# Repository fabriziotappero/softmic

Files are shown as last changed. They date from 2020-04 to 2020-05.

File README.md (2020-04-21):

# Software-Defined Microphone

This is the home of *Software-Defined Microphone*, a quite special
high-quality wireless microphone designed to allow you to focus on the artistic
aspect of sound recording.

The basic idea is a microphone that includes all the necessary on-board 
software so that compression, noise reduction, volume control is magically done
by the microphone itself. The ultimate goal of this microphone is to let the
microphone take care of the technicalities so that you can concentrate on the 
artistic aspect of sound recording.

In this picture you can see a the first prototype of *Software-Defined Microphone*.

<p align="center">
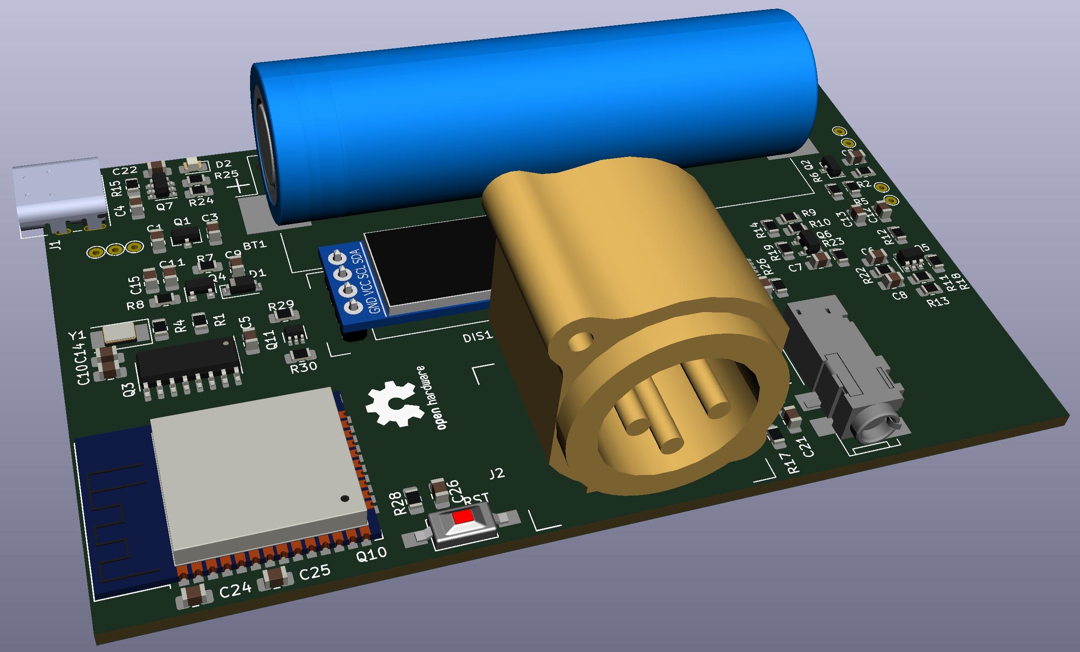
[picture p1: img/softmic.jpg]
  
</p>

*Software-Defined Microphone* is completely  open source: schematics, circuit 
simulations, mechanical drawings and software code.

## Repository Folder Structure
This is the folder structure of this project.
```
root
│   README.md               The file your are reading
│   license.md              License file    
└───sch                     Schematics and PCB fab files done in KiCad
│   │   softmic.pro
│   │   softmic.sch
│   │   softmic.kicad_pcb
│   └───lib                 Kicad library files
│   └───pdf                 IC data sheets
└───sim                     Simulated circuits in LT Spice
│   │   softmic-sim.asc
│   └───lib                 LT Spice library  
└───src                     Micropython ESP32 code
└───mec                     Mechanical parts designed in Blender
└───img                     Various images
└───tmp                     generic data sheets and additional info
```
## Starting point
I actually own a [Samson C02](https://www.amazon.com/s?k=samsons+c02) condenser
microphone that I use together with a [Tascam DR-40](https://www.amazon.com/s?k=tascam+dr-40).
[Here](https://soundcloud.com/cinema_sound/samson-c02-dx-pop-filter) 
an example of what the Samson C02 sounds like 
and following, the picture of the inside of my Samson C02.

<p align="center">
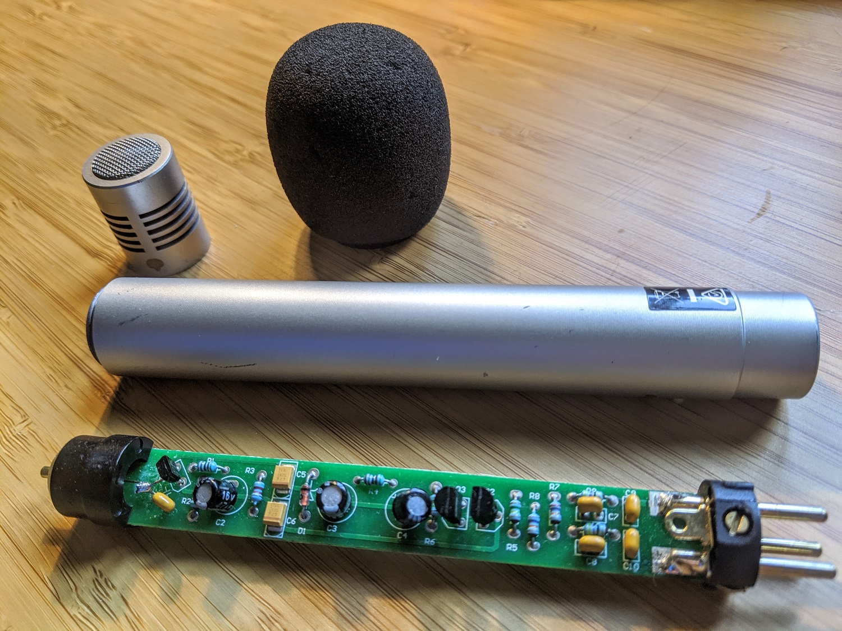
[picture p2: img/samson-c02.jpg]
  
</p>
Here you can see the actual schematic of the Samson C02 (courtesy of *the Internet*). 
Nothing really mind-blowing but functional.
<p align="center">
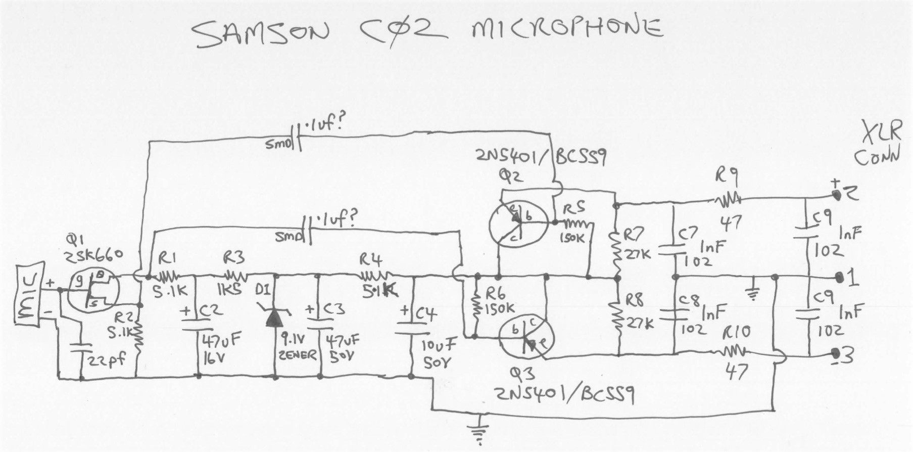
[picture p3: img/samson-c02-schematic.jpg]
  
</p>

For the time being this is the starting point of this project. The objective of 
this project is to make something of a similar quality but *software-oriented*.

## Microphone Capsule
This microphone is designed to function with an **electret capsule** similar to the
[Primo EM173](sch/pdf/PrimoEM173.pdf), an
electret capsule with an internal FET. For some additional flexibility the use of
a simpler electret capsule without FET (e.g. the 
[Transsound TSB160A](img/TSB160A.jpg) from the 
Samson C02) will be possible too.

## Microphone System Design
Let us see a detailed list of features of this microphone. Some of these features
are still unimplemented.

1. The microphone uses a standard **electret microphone capsule** with a standard 
 internal FET. The use of a electret microphone without FET is possible too.

2. a traditional 3.5mm stereo headphone jack output (unbalanced line out) allows 
the microphone to be connected to a pair of standard headphones for monitoring 
purposes.

3. A standard XLR connector offers a balanced audio output. This allows this
microphone to be interfaced with any traditional audio equipment.

4. When provided externally via the XLR connector, phantom power can power the 
microphone. (UNIMPLEMENTED)

5. A Bluetooth/WiFi output allows to connect without cables to a camera, 
smartphone or PC.

6. When using Bluetooth/WiFi, multiple microphones can be all connected among
them. (UNIMPLEMENTED)

7. An internal 1-cell lithium battery can power the microphone for approximately
10h. This battery is rechargeable via a USB-C connector.

4. When provided externally via the XLR connector, phantom power can recharge the 
internal lithium battery. (UNIMPLEMENTED)

8. The microphone is equipped with a fairly powerful dual-core
processor re-programmable over the WiFi connection or over USB-C. The processor
programming is done in [Micropython](https://micropython.org/).

9. To ease connectivity with other accessories the microphone is equipped
with one-does-it-all small multi-pin connector. (UNIMPLEMENTED)

10. A spring connector similar to the 
[Coda Systems PCB sprint connector](img/codaSystemsSpringConn.jpg) allows the 
microphone to be connected to or power other accessories. (UNIMPLEMENTED)

11. A small LCD outputs all necessary microphone information.

12. Few push buttons allow to interact with the microphone.

13. The internal ESP32 dual-core processor allows the realtime processing of the
audio signal coming in. (UNIMPLEMENTED)

## Circuit Schematics
In the following figure you can see the KiCad schematic of softmic done in KiCad.

<p align="center">
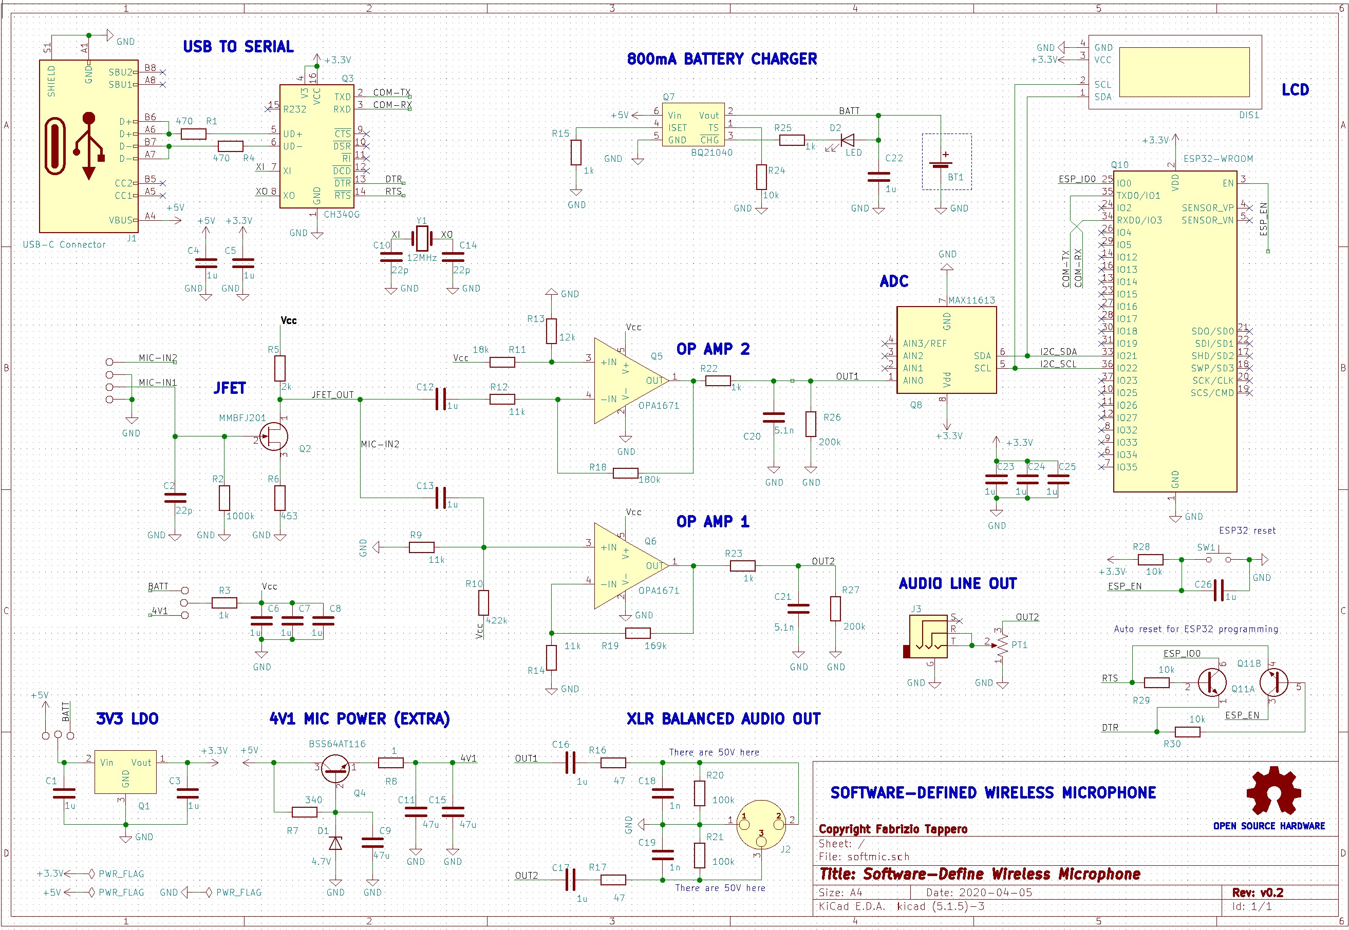
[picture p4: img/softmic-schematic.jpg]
  
</p>

## Mechanical Parts
A full fledged microphone is not only made of its electronics, mechanical parts 
are equally important.

Any mechanical parts in this projects are made with non-destructive modeling 
using [Blender](https://www.blender.org) version 2.8. 
For a quick start have a look at this 
[great tutorial](https://www.youtube.com/watch?v=WzwmkYhlrcQ).

## License
Copyright (c) 2020 Fabrizio Tappero

Permission is hereby granted, free of charge, to any person obtaining a copy of 
this software and associated documentation files (the "Software"), to deal in 
the Software without restriction, including without limitation the rights to 
use, copy, modify, merge, publish, distribute, sublicense, and/or sell copies 
of the Software, and to permit persons to whom the Software is furnished to do 
so, subject to the following conditions:

The above copyright notice and this permission notice shall be included in all 
copies or substantial portions of the Software.

THE SOFTWARE IS PROVIDED "AS IS", WITHOUT WARRANTY OF ANY KIND, EXPRESS OR 
IMPLIED, INCLUDING BUT NOT LIMITED TO THE WARRANTIES OF MERCHANTABILITY, 
FITNESS FOR A PARTICULAR PURPOSE AND NONINFRINGEMENT. IN NO EVENT SHALL THE 
AUTHORS OR COPYRIGHT HOLDERS BE LIABLE FOR ANY CLAIM, DAMAGES OR OTHER 
LIABILITY, WHETHER IN AN ACTION OF CONTRACT, TORT OR OTHERWISE, ARISING 
FROM, OUT OF OR IN CONNECTION WITH THE SOFTWARE OR THE USE OR OTHER 
DEALINGS IN THE SOFTWARE.

## References
A lot of microphone and microphone-related products and devices exists out there.
Here is what it can be considered a good starting point.

[Electret microphone](ttps://sound-au.com/articles/mic-electret.htm) and their
[electret Capsule](http://www.firstpr.com.au/rwi/mics/2009-09-a/).

[Microphone capsule Manufacturer](https://www.jlielectronics.com/microphone-capsules/?sort=pricedesc)
and one more [ capsule Manufacturer](https://microphone-parts.com/collections/capsules).

[Extensive RODE guy lecturer](https://www.youtube.com/watch?v=yKOH0DyRWRU&list=PLHoGZ7nuFTo8VmQBhzZxl-qDEIN7T5Vt8).
and some [audio Microphone Kits](https://microphone-parts.com/collections/mod-kits).

[Electret Amplifier Circuits](http://xtremecircuits.blogspot.com/2012/09/compressor-for-electret-microphone.html).

Some Texas instruments IC, [here](https://www.ti.com/lit/an/sboa320a/sboa320a.pdf) and 
[here](http://www.ti.com/lit/ug/tidu765/tidu765.pdf).

if you google *TS971 based Electret Condenser Microphone Amplifier* you get:
[this](https://robbietrumpet.com/soundcatchers.net/studio_recording_sound.htm), 
[this](https://www.instructables.com/id/Modify-a-cheap-LDC-Condenser-microphone/), 
[this](http://www.sdiy.org/oid/mics/Schoeps.gif) and 
[this](http://www.zen22142.zen.co.uk/Circuits/Audio/ecmmic.htm).

[Some electret capsules](https://www.abcomponents.co.uk/product-category/electret-microphones/) and 
[this](https://micbooster.com/12-primo-microphone-capsules) and 
[this](https://micbooster.com/content/12-comparison-table-for-primo-microphone-capsules).

Very interesting [electret capsules](https://micbooster.com/primo-microphone-capsules/9-em173.html)
and [some more](https://micbooster.com/primo-microphone-capsules/8-primo-em172.html) plus the 
[very best electret capsule](http://www.micbooster.com/documents/EM173%20Oct%202011.pdf).

[Application Note about LSK489](http://www.linearsystems.com/lsdata/others/LSK489_Application_Note.pdf).

[Interesting capacity multiplier](http://www.audioimprov.com/AudioImprov/Mics/Entries/2014/12/18_Another_Chinese_mic_Circuit.html).

[Samson C02 internal circuit](http://www.audioimprov.com/AudioImprov/Mics/Entries/2015/4/23_Basic_FET_Microphone_Circuits.html).

[Popular Alice schematic](http://scotthelmke.com/alice-mic.html).

[How to bias a JFET](http://www.vishay.com/docs/70595/70595.pdf).

[Audio compressor](https://www.electroschematics.com/audio-compressor-agc/).

[Audio Op Amp IC from Texas Instrument](http://www.ti.com/lit/ds/symlink/opa1678.pdf).

Interesting [blog post](https://www.diyaudio.com/forums/equipment-and-tools/319784-search-ultra-quality-electret-mic-interface-circuit.html) and 
[here](https://www.electronics-lab.com/project/low-noise-mini-electret-microphone-preamplifier/),
[here](http://www.johncon.com/john/wm61a/) 
and [here](http://www.micbooster.com/documents/EM173%20Oct%202011.pdf).

[Interesting audio people](https://micbooster.com/)

[Interesting microphone case](https://eu.mouser.com/Wire-Cable/Wire-Cable-Management/Cable-Glands-Strain-Reliefs-Cord-Grips/_/N-fb8zo) and [one more](https://eu.mouser.com/datasheet/2/18/inhouse_Amphenol_C146%20Series_Accessories_VN16-1158081.pdf).

[Audio Preamp product](https://www.bhphotovideo.com/c/product/292989-REG/Sound_Devices_MM_1_MM_1_Single_Channel_Portable.html/overview) and one more 
[reference audio preamp](http://www.hiroshi.com.hk/en/product/detail/mini-microphone-pre-amplifier-23#.Xn4073Io_ws)
that I actually own.

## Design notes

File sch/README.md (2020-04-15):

Schematic files for the creation of the PCB done using the open-source software KICAD available from:

https://www.kicad-pcb.org/

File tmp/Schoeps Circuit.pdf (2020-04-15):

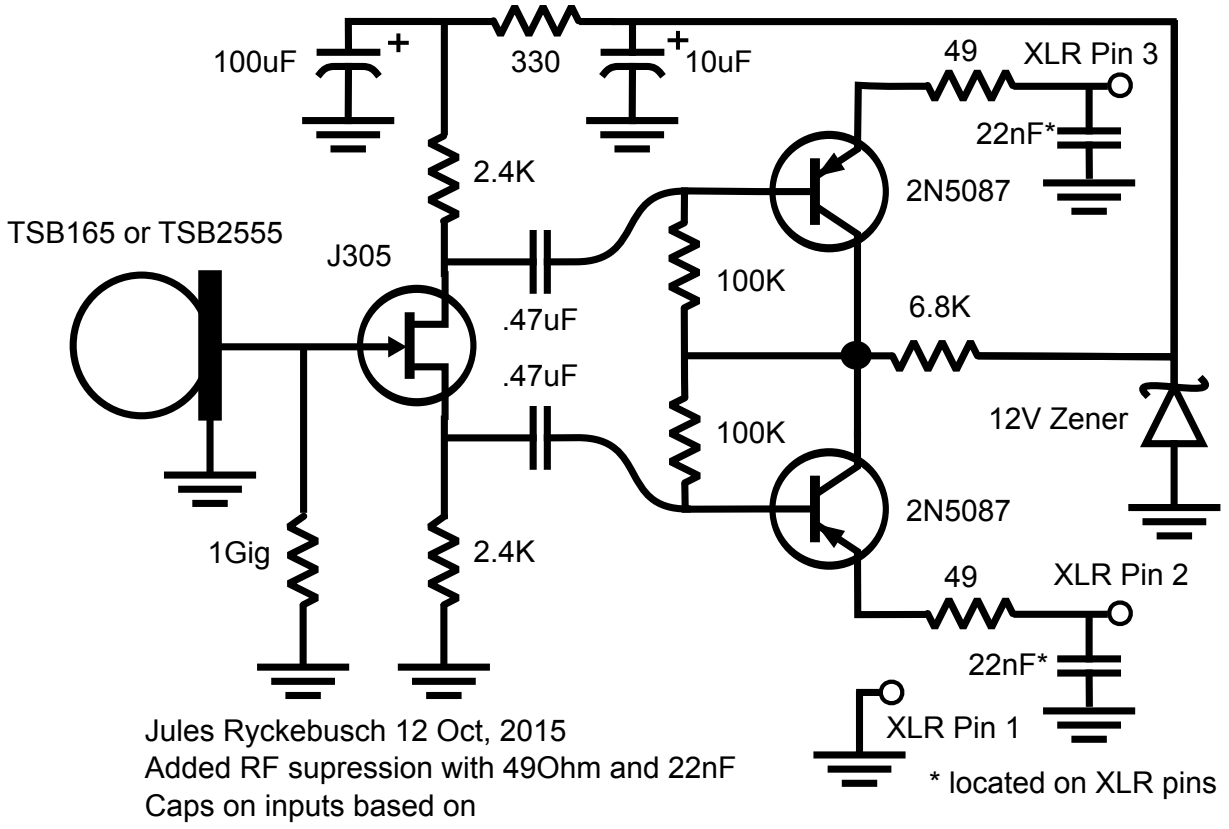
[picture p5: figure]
XLR Pin 1; XLR Pin 2; XLR Pin 3 100uF; 12V Zener; Jules Ryckebusch 12 Oct, 2015 Added RF supression with 49Ohm and 22nF Caps on inputs based on; * located on XLR pins; 1Gig; TSB165 or TSB2555

Scott Helmke "Alice" Mic Schoeps Circuit

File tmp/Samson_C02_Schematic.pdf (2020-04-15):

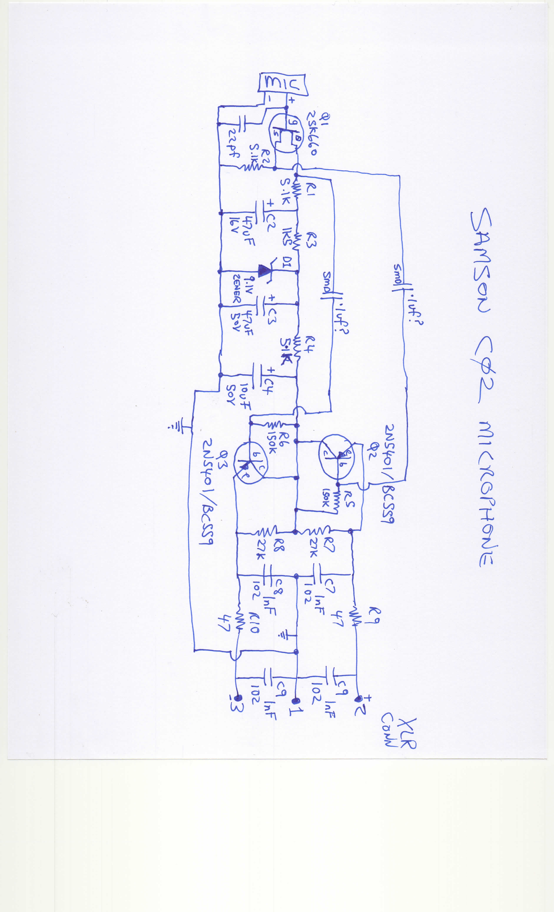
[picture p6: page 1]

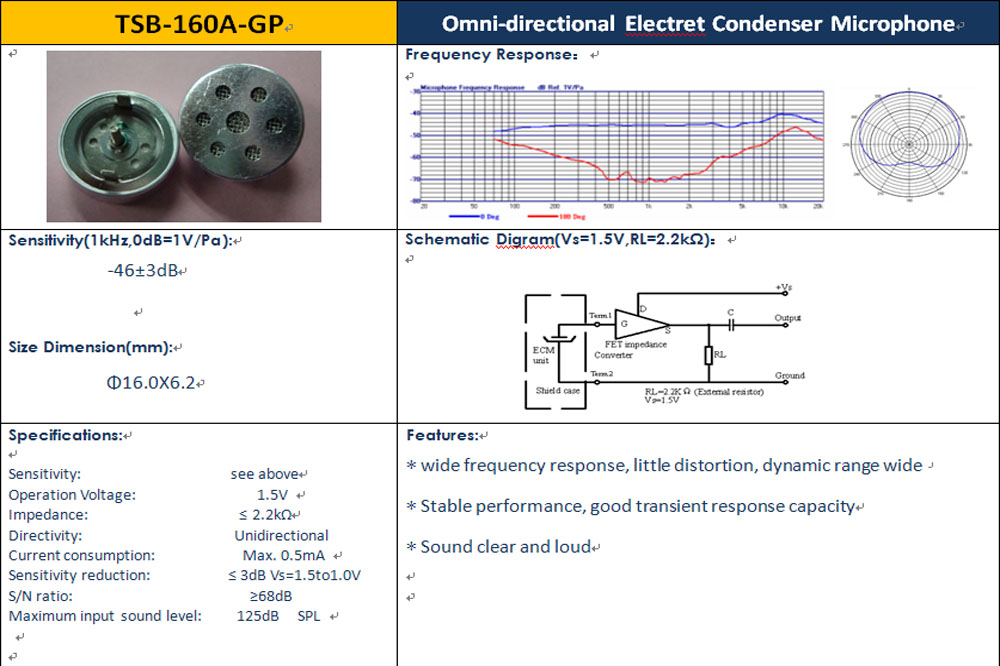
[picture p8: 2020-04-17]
img/TSB160A.jpg

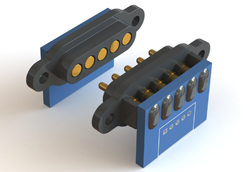
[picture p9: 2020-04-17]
img/codaSystemsSpringConn.jpg

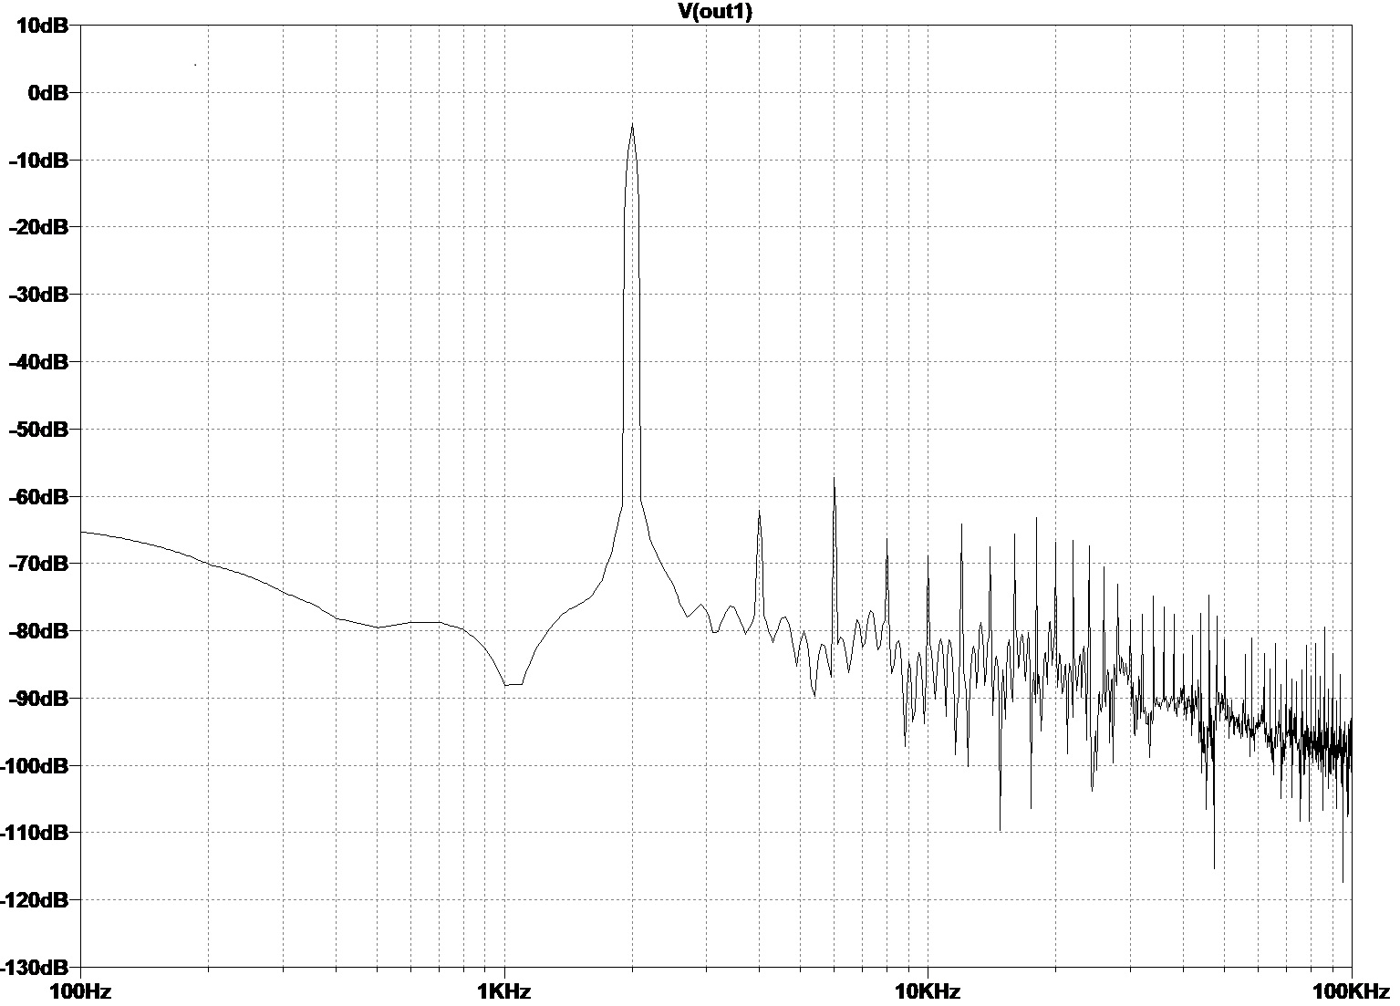
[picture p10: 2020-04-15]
sim/ALL-FFT.jpg

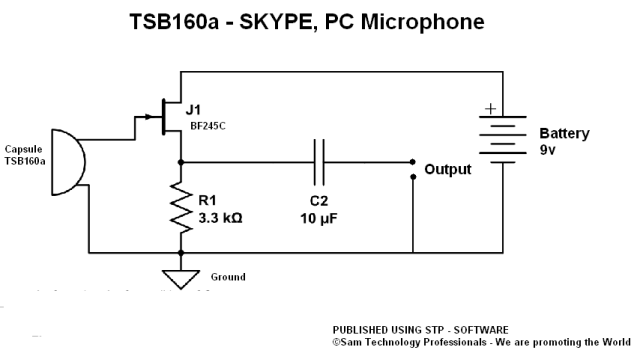
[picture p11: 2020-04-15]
tmp/TSB160A.png

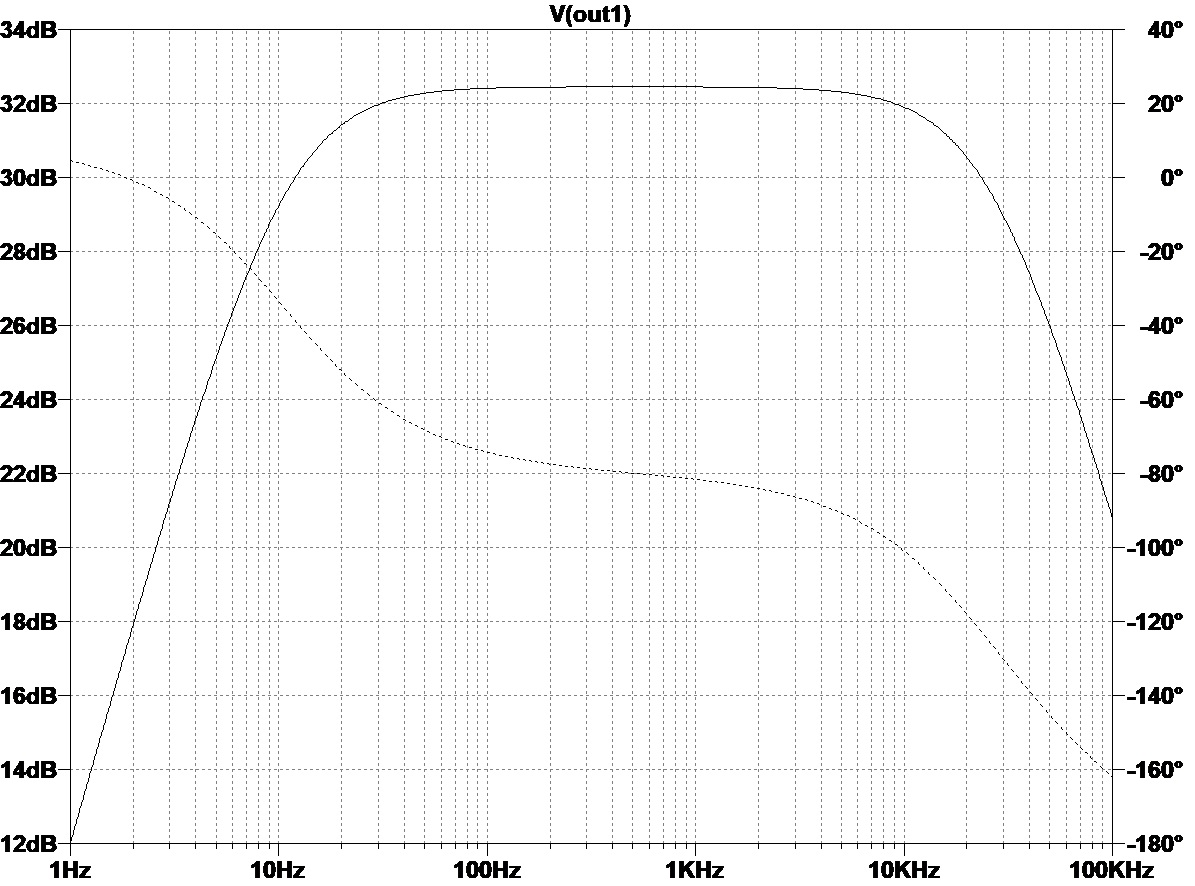
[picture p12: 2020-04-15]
sim/ALL-BW.jpg

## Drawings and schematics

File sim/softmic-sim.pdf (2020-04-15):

# Audio Pre Amplifier, 32dB gain, 20Hz to 20kHz at -1dB bandwidth

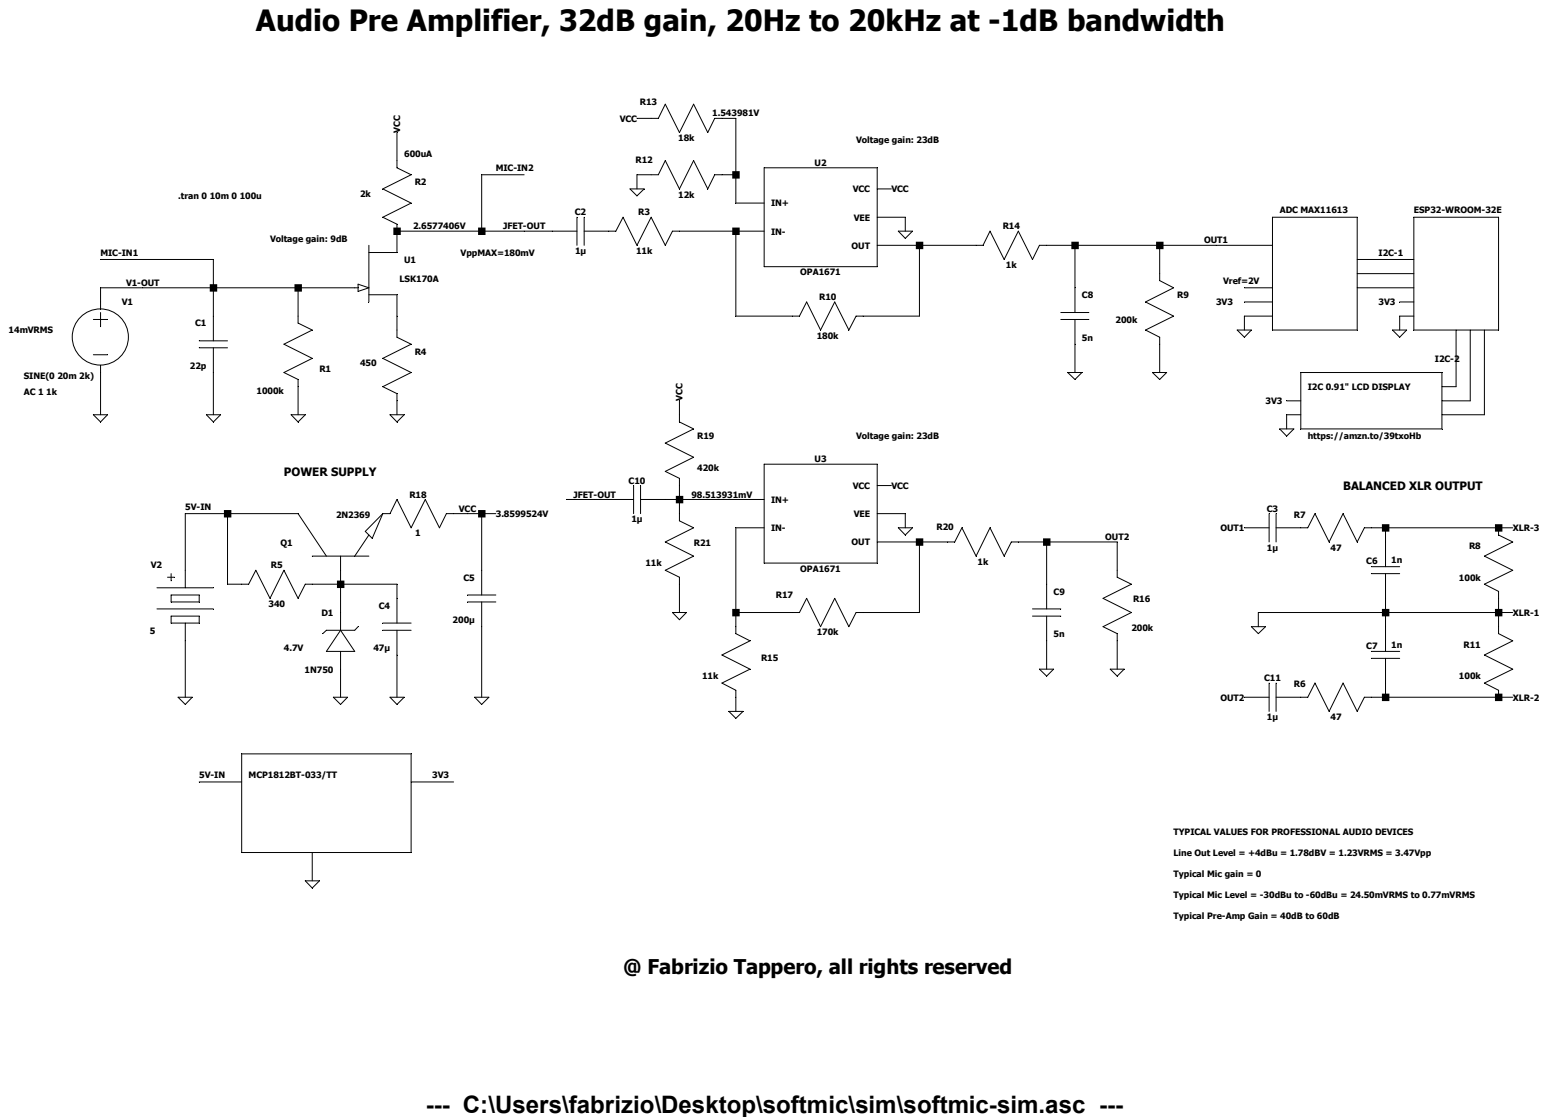
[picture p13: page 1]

TYPICAL VALUES FOR PROFESSIONAL AUDIO DEVICES

Typical Mic Level = -30dBu to -60dBu = 24.50mVRMS to 0.77mVRMS

Typical Pre-Amp Gain = 40dB to 60dB

@ Fabrizio Tappero, all rights reserved

--- C:\Users\fabrizio\Desktop\softmic\sim\softmic-sim.asc ---

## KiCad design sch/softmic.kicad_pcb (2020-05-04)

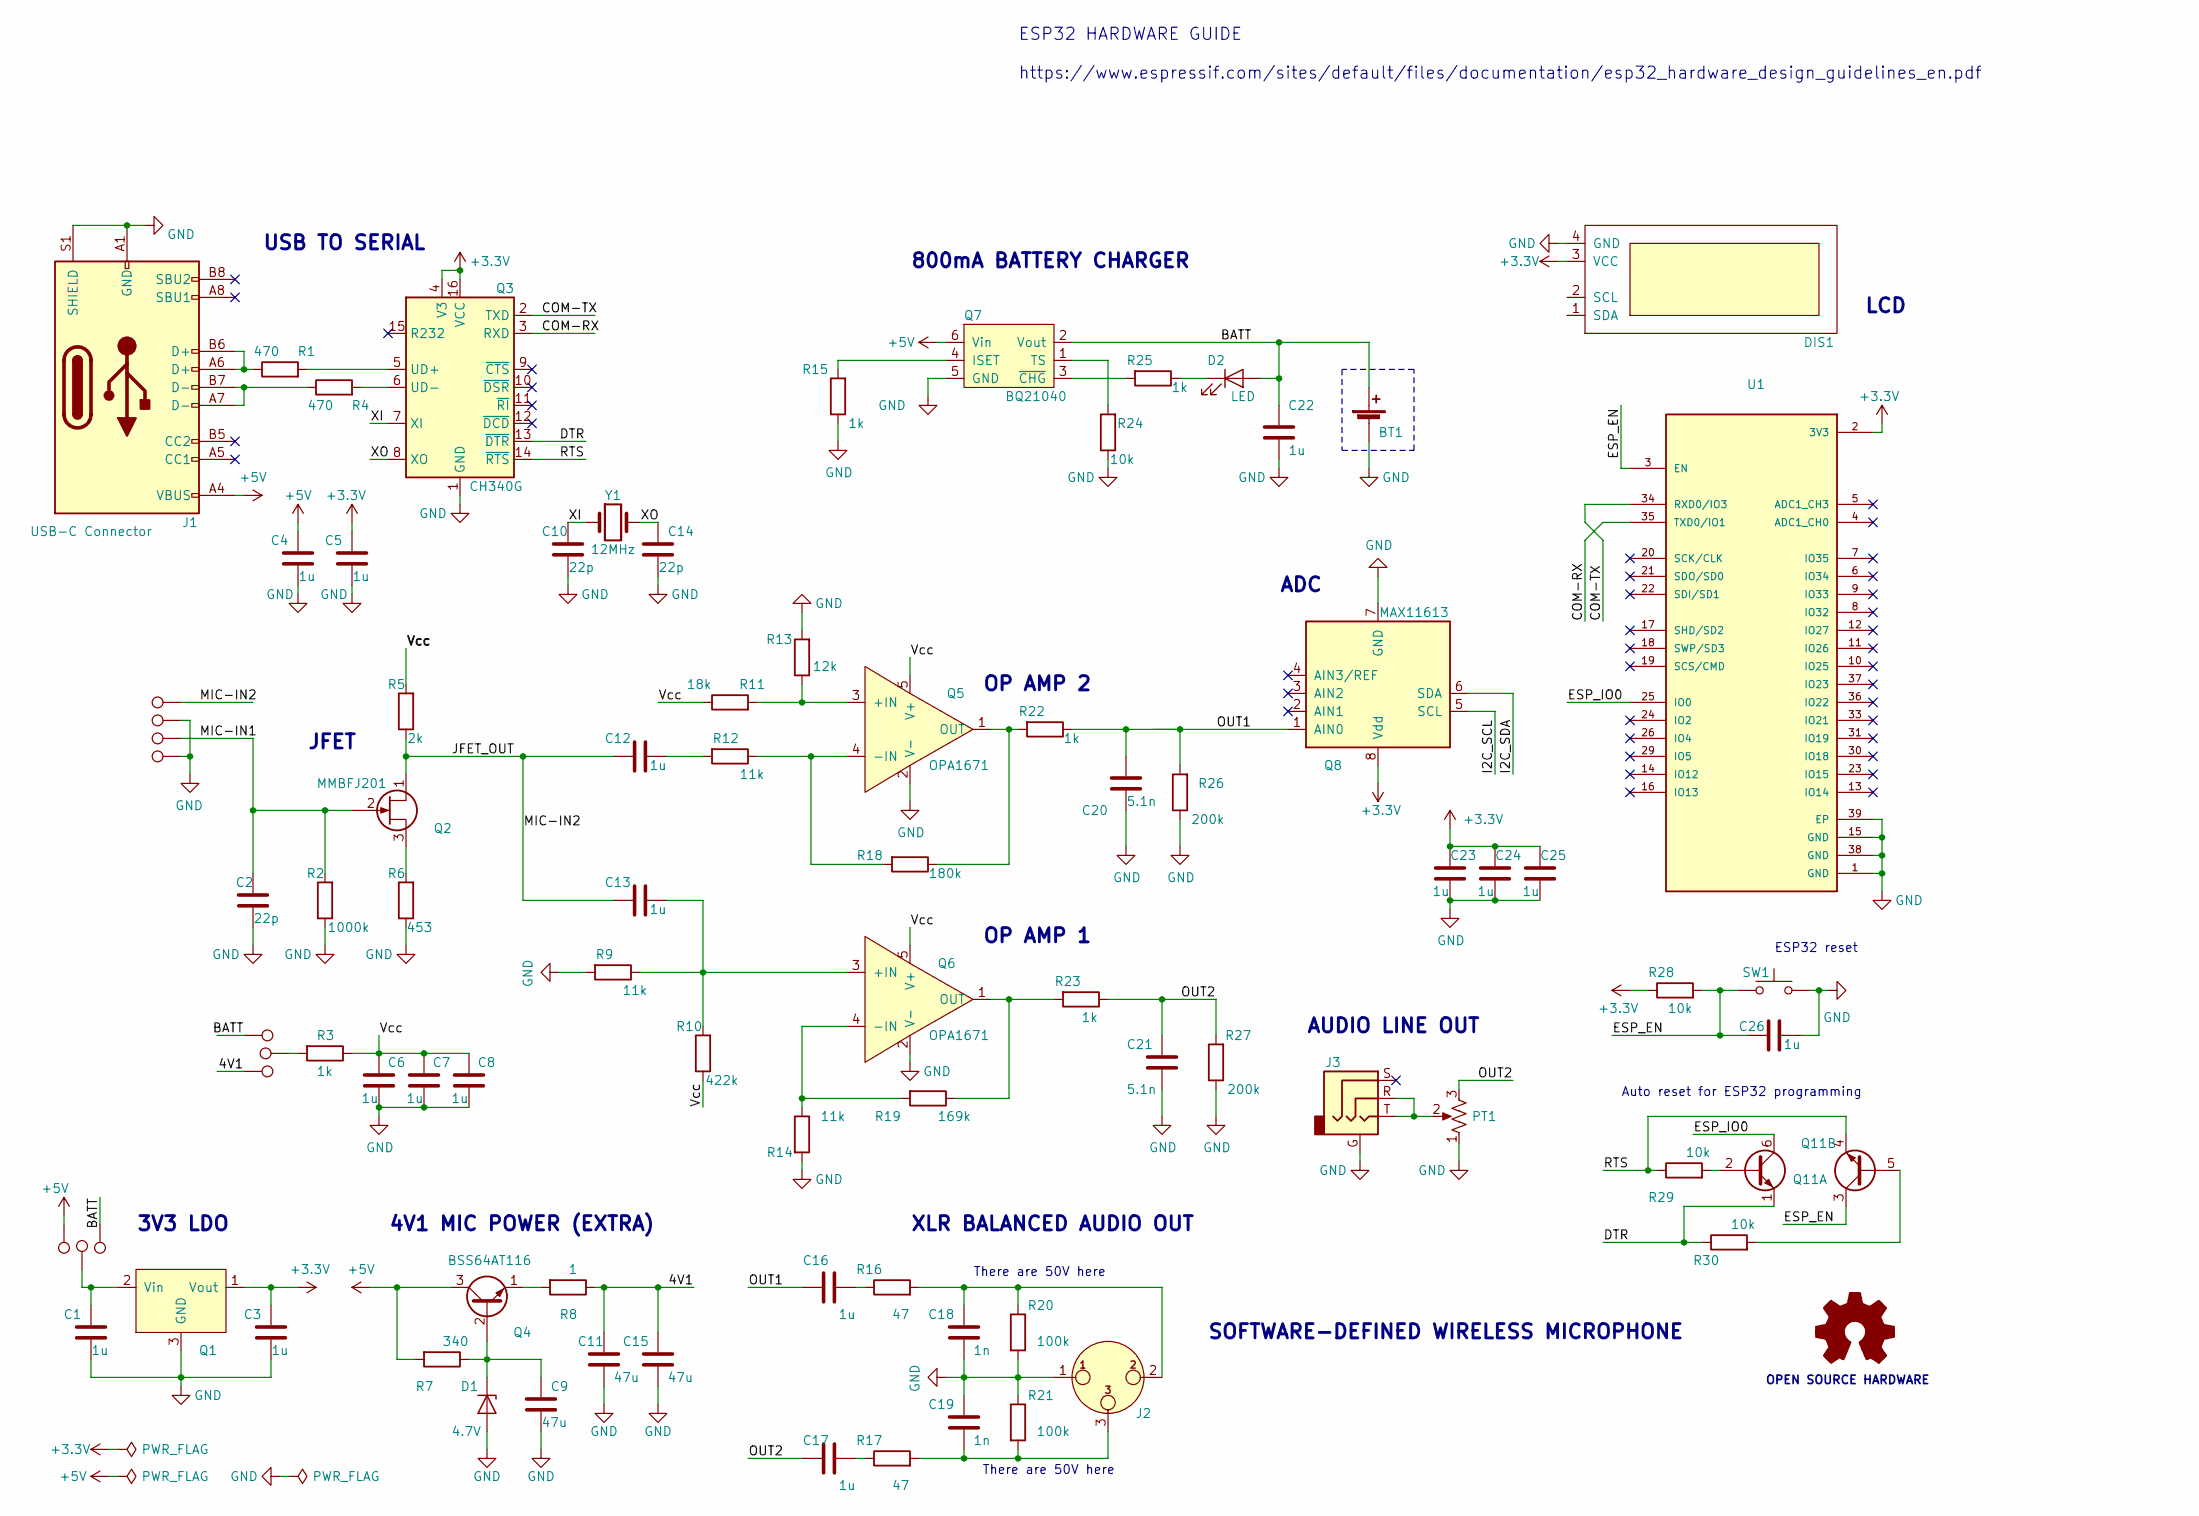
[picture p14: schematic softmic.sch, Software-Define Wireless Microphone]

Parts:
BT1: 1-Cell Litium Battery; BatteryHolder18650; Mouser PN none; Digikey PN none
C1, C3, C4, C5, C6, C7, C8, C12, C13, C16, C17, C22, C23, C24, C25, C26: 1u; C_0805_2012Metric_Pad1.15x1.40mm_HandSolder; MPN HMK212BC7105MGHT; Digikey PN none
C2, C10, C14: 22p; C_0805_2012Metric_Pad1.15x1.40mm_HandSolder; MPN none; Digikey PN none
C9, C11, C15: 47u; C_0805_2012Metric_Pad1.15x1.40mm_HandSolder; MPN LMK316BC6476ML-T; Digikey PN none
C18, C19: 1n; C_0805_2012Metric_Pad1.15x1.40mm_HandSolder; MPN none; Digikey PN none
C20, C21: 5.1n; C_0805_2012Metric_Pad1.15x1.40mm_HandSolder; MPN none; Digikey PN none
D1: 4.7V; D_SOD-123; MPN BZT52C4V7-E3-08; Digikey PN 112-BZT52C4V7-E3-08CT-ND
D2: LED; LED_0805_2012Metric_Pad1.15x1.40mm_HandSolder; Mouser PN 710-150080RS75000; Digikey PN 732-4984-1-ND
DIS1: Oled_128_32; OLED-0.91-128x32; MPN none; Digikey PN none
J1: USB-C Connector; USB_C_Receptacle_GCT_USB4085; MPN USB4085-GF-A; Digikey PN 2073-USB4085-GF-ACT-ND
J2: XLR-OUT; XLR-NC3MAAH-1; MPN NC3MAAH-1; Digikey PN none
J3: AudioJack 3.5mm; SJ-43514-SM; MPN SJ-43514-SMT-TR; Digikey PN CP-43514SJCT-ND
P1, P2, P3, P8, P9: 4V1; TestPoint_THTPad_D1.5mm_Drill0.7mm; MPN none; Digikey PN none
P4, P5, P6, P7: none; TestPoint_THTPad_D1.5mm_Drill0.7mm; MPN none; Digikey PN none
P10: VccPad; TestPoint_THTPad_D1.5mm_Drill0.7mm; MPN none; Digikey PN none
PT1: 200k; Potentiometer_Bourns_3224W_Vertical; MPN PVG3G204C01R00; Digikey PN PVG3G204C01R00
Q1: MCP1812BT-033; SOT-23; MPN MCP1812BT-033/TT; Digikey PN MCP1812BT-033/TTTR-ND
Q2: MMBFJ201; SOT-23; MPN MMBFJ201; Digikey PN MMBFJ201CT-ND
Q3: CH340G; SOIC-16_3.9x9.9mm_P1.27mm; MPN CH340G; LCSC PN C14267
Q4: BSS64AT116; SOT-23; MPN BSS64AT116; Digikey PN BSS64AT116CT-ND
Q5, Q6: OPA1671; SOT-23-5; MPN OPA1671IDBVR; Digikey PN 296-OPA1671IDBVRCT-ND
Q7: BQ21040; SOT-23-6; MPN BQ21040DBVT; Digikey PN 296-44196-1-ND
Q8: MAX11613; MSOP-8_3x3mm_P0.65mm; MPN MAX11613EUA+T; Digikey PN MAX11613EUA+CT-ND
Q11: BC847BS-TP; SOT-363_SC-70-6; Mouser PN 833-BC847BS-TP
R1, R4: 470; R_0805_2012Metric_Pad1.15x1.40mm_HandSolder; MPN none; Digikey PN none
R2: 1000k; R_0805_2012Metric_Pad1.15x1.40mm_HandSolder; MPN none; Digikey PN none
R3, R15, R22, R23, R25: 1k; R_0805_2012Metric_Pad1.15x1.40mm_HandSolder; MPN none; Digikey PN none
R5: 2k; R_0805_2012Metric_Pad1.15x1.40mm_HandSolder; MPN none; Digikey PN none
R6: 453; R_0805_2012Metric_Pad1.15x1.40mm_HandSolder; MPN none; Digikey PN none
R7: 340; R_0805_2012Metric_Pad1.15x1.40mm_HandSolder; MPN none; Digikey PN none
R8: 1; R_0805_2012Metric_Pad1.15x1.40mm_HandSolder; MPN none; Digikey PN none
R9, R12, R14: 11k; R_0805_2012Metric_Pad1.15x1.40mm_HandSolder; MPN none; Digikey PN none
R10: 422k; R_0805_2012Metric_Pad1.15x1.40mm_HandSolder; MPN none; Digikey PN none
R11: 18k; R_0805_2012Metric_Pad1.15x1.40mm_HandSolder; MPN none; Digikey PN none
R13: 12k; R_0805_2012Metric_Pad1.15x1.40mm_HandSolder; MPN none; Digikey PN none
R16, R17: 47; R_0805_2012Metric_Pad1.15x1.40mm_HandSolder; MPN none; Digikey PN none
R18: 180k; R_0805_2012Metric_Pad1.15x1.40mm_HandSolder; MPN none; Digikey PN none
R19: 169k; R_0805_2012Metric_Pad1.15x1.40mm_HandSolder; MPN none; Digikey PN none
R20, R21: 100k; R_0805_2012Metric_Pad1.15x1.40mm_HandSolder; MPN none; Digikey PN none
R24, R28, R29, R30: 10k; R_0805_2012Metric_Pad1.15x1.40mm_HandSolder; MPN none; Digikey PN none
R26, R27: 200k; R_0805_2012Metric_Pad1.15x1.40mm_HandSolder; MPN none; Digikey PN none
SW1: RST; SW_SPST_FSMSM; MPN PTS636SM43SMTRLF; Digikey PN none
U1: ESP32-WROVER-B 16MB; ESP32-WROVER-B_(16MB); MPN ESP32-WROVER-B (16MB); LCSC PN none
Y1: 12MHz; Crystal_SMD_5032-2Pin_5.0x3.2mm; MPN TCX Corporation; LCSC PN none
logo1: Logo_Open_Hardware_Small; OSHW-Logo2_9.8x8mm_SilkScreen

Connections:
+3V3: C3.2, C5.2, C23.2, C24.2, C25.2, DIS1.3 (VCC), Q1.1 (Vout), Q3.4 (V3), Q3.16 (VCC), Q8.8 (Vdd), R28.1, U1.2 (3V3)
+5V: C4.2, J1.A4 (VBUS), J1.A9 (VBUS), J1.B4 (VBUS), J1.B9 (VBUS), P1.1, Q4.3 (C), Q7.6 (Vin), R7.2
/4V1: C11.1, C15.1, P9.1, R8.1
/BATT: BT1.1 (+), C22.2, D2.2 (A), P3.1, P8.1, Q7.2 (Vout)
/COM-RX: Q3.3 (RXD), U1.35 (TXD0/IO1)
/COM-TX: Q3.2 (TXD), U1.34 (RXD0/IO3)
/DTR: Q3.13 (~DTR), Q11.1 (E1), R30.1
/ESP_EN: C26.2, Q11.3 (C2), R28.2, SW1.1, U1.3 (EN)
/ESP_IO0: Q11.6 (C1), U1.25 (IO0)
/I2C_SCL: Q8.5 (SCL)
/I2C_SDA: Q8.6 (SDA)
/JFET_OUT: C12.2, C13.2, P4.1, Q2.1 (D), R5.1
/MIC-IN1: C2.1, P6.1, Q2.2 (G), R2.2
/OUT1: C16.2, C20.1, Q8.1 (AIN0), R22.1, R26.2
/OUT2: C17.2, C21.1, PT1.3, R23.1, R27.2
/RTS: Q3.14 (~RTS), Q11.4 (E2), R29.1
/Vcc: C6.2, C7.2, C8.2, Q5.5 (V+), Q6.5 (V+), R3.1, R5.2, R10.1, R11.1
/XI: C10.1, Q3.7 (XI), Y1.1
/XO: C14.1, Q3.8 (XO), Y1.2
GND: BT1.2 (-), C1.1, C2.2, C3.1, C4.1, C5.1, C6.1, C7.1, C8.1, C9.2, C10.2, C11.2, C14.2, C15.2, C18.1, C19.2, C20.2, C21.2, C22.1, C23.1, C24.1, C25.1, C26.1, D1.2 (A), DIS1.4 (GND), J1.A1 (GND), J1.A12 (GND), J1.B1 (GND), J1.B12 (GND), J1.S1 (SHIELD), J2.1, J3.G, P5.1, P7.1, PT1.1, Q1.3 (GND), Q3.1 (GND), Q5.2 (V-), Q6.2 (V-), Q7.5 (GND), Q8.7 (GND), R2.1, R6.1, R9.2, R13.2, R14.2, R15.1, R20.2, R21.1, R24.1, R26.1, R27.1, SW1.2, U1.1 (GND), U1.15 (GND), U1.38 (GND), U1.39 (EP)
unnamed: C1.2, P2.1, Q1.2 (Vin)
unnamed: C9.1, D1.1 (K), Q4.2 (B), R7.1
unnamed: C12.1, R12.2
unnamed: C13.1, Q6.3 (+IN), R9.1, R10.2
unnamed: C16.1, R16.1
unnamed: C17.1, R17.1
unnamed: C18.2, J2.2, R16.2, R20.1
unnamed: C19.1, J2.3, R17.2, R21.2
unnamed: D2.1 (K), R25.1
unnamed: J1.A6 (D+), J1.B6 (D+), R1.1
unnamed: J1.A7 (D-), J1.B7 (D-), R4.1
unnamed: J3.R, J3.T, PT1.2
unnamed: P10.1, R3.2
unnamed: Q2.3 (S), R6.2
unnamed: Q3.5 (UD+), R1.2
unnamed: Q3.6 (UD-), R4.2
unnamed: Q4.1 (E), R8.2
unnamed: Q5.1 (OUT), R18.1, R22.2
unnamed: Q5.3 (+IN), R11.2, R13.1
unnamed: Q5.4 (-IN), R12.1, R18.2
unnamed: Q6.1 (OUT), R19.1, R23.2
unnamed: Q6.4 (-IN), R14.1, R19.2
unnamed: Q7.1 (TS), R24.2
unnamed: Q7.3 (~CHG), R25.2
unnamed: Q7.4 (ISET), R15.2
unnamed: Q11.2 (B1), R29.2
unnamed: Q11.5 (B2), R30.2

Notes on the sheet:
OPEN SOURCE HARDWARE
3V3 LDO
XLR BALANCED AUDIO OUT
OP AMP 1
OP AMP 2
JFET
800mA BATTERY CHARGER
ADC
USB TO SERIAL
LCD
SOFTWARE-DEFINED WIRELESS MICROPHONE
4V1 MIC POWER (EXTRA)
AUDIO LINE OUT
ESP32 HARDWARE GUIDE https://www.espressif.com/sites/default/files/documentation/esp32_hardware_design_guidelines_en.pdf
Auto reset for ESP32 programming
ESP32 reset
There are 50V here

Board: 2 copper layers, 87 parts (0 on the bottom side), 45 nets, no tracks yet.

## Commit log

2020-04-15 added schematic
2020-04-18 added PDF datasheet of 3.5mm jack audio connector and ldo substitute for 3V3 output from 1-cell lithium battery
2020-04-18 in schematic, now LDO input can be USB 5V or internal battery
    [softmic.sch]
2020-04-18 added line out audio jack in schematic and PCB
    [softmic.kicad_pcb, softmic.sch]
2020-04-20 changed USB to serial IC, changed some footprints, changed RST SW
    [softmic.kicad_pcb, softmic.sch]
2020-04-20 changed USB-C connector type
    [softmic.kicad_pcb, softmic.sch]
2020-04-21 changed USB-C footprint and battery holder
    [softmic.kicad_pcb, softmic.sch]
2020-04-21 added small headphone volume potentiomenter
    [softmic.kicad_pcb, softmic.sch]
2020-04-21 changed all resistors to 0805 case resistors
    [softmic.kicad_pcb, softmic.sch]
2020-04-21 change all caps to 0805 case caps
    [softmic.kicad_pcb, softmic.sch]
2020-04-21 changed LED to red 0805 led
    [softmic.kicad_pcb, softmic.sch]
2020-04-21 pcb components placed
    [softmic.kicad_pcb, softmic.sch]
2020-04-21 schematic pdf updated
2020-05-04 changed ESP32 module for the 16MB version
    [softmic.kicad_pcb, softmic.sch]

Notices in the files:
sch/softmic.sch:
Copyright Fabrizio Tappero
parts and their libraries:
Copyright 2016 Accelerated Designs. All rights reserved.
